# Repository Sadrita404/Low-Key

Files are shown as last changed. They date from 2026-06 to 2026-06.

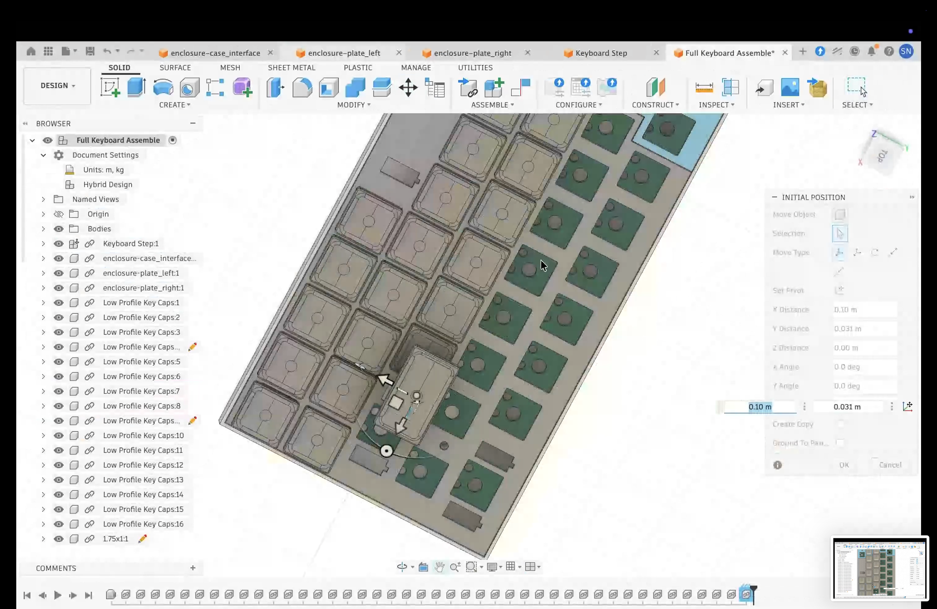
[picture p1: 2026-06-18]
IMAGES/22.png

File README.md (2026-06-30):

<div align="center">
  <table border="0" cellpadding="0" cellspacing="0">
    <tr>
      <td align="center" style="background: #ffffff; border: 1px solid #d0d7de; border-radius: 12px; padding: 16px; box-shadow: 0 4px 12px rgba(0,0,0,0.05);">
        Rough Layout For The PCB
        <div style="margin-top: 12px; font-family: -apple-system, BlinkMacSystemFont, 'Segoe UI', Helvetica, Arial, sans-serif; font-size: 13px; color: #57606a; font-weight: 500;">
      </td>
    </tr>
  </table>
</div>

|Title | Low Key |
|:-- |:--|
|Author | Sadrita Neogi|

## Overview
It is a 60% Low Profile Keyboard trying to build an mac magic keyboard alternative. And for this project I have choose the Promicro NRF52840 Controller Board as it is cost effective and easy to setup . I have also make this keyboard too low profile so that it can be easy to type in it . I have also make it battery powered and It can be worked over bluetooth that makes it very easy to use.

### Why I choose this project?
I have choose this project because I have a big fan of the Apple magic keyboard due to its low profile and good looking so from the starting I wanted to create something like which is low profile. But if I going to buy one, it would cost me a lot and I cannot customise it so I wanted to make something which is customisable, so I have made this in the 60% layout keyboard which is in the low profile and I love to make it and I have also made the PCB so I can customise it. I have also put my name on the PCB. And I have loved the whole process from designing in the PCB to making assembly file in fusion

<div id="-screenshots" align="center">
  <h3>PCB Design</h3>

  <table>
    <tr>
      <td>
        Full Board Layout
      </td>
      <td>
        Component Placement
      </td>
    </tr>
    <tr>
      <td>
        Trace Routing Detail
      </td>
      <td>
        Connection Map
      </td>
    </tr>
  </table>
</div>

<div id="-screenshots" align="center">
  <h3>PCB </h3>

  <table>
    <tr>
      <td>
        Full Board Layout
      </td>
      <td>
        Component Placement
      </td>
    </tr>
    <tr>
      <td>
        Trace Routing Detail
      </td>
      <td>
        Connection Map
      </td>
    </tr>
  </table>
</div>

<div id="-screenshots" align="center">
  <h3>CAD Work </h3>

  <table>
    <tr>
      <td>
        Full Board Layout
      </td>
      <td>
        Component Placement
      </td>
    </tr>
    <tr>
      <td>
        Trace Routing Detail
      </td>
      <td>
        Connection Map
      </td>
    </tr>
  </table>
</div>

<div id="-screenshots" align="center">
  <h3> Assembly CAD Work </h3>
  <table>
    <tr>
      <td>
        Full Board Layout
      </td>
      <td>
        Component Placement
      </td>
    </tr>
    <tr>
      <td>
        Trace Routing Detail
      </td>
      <td>
        Connection Map
      </td>
    </tr>
  </table>
</div>

<!-- FRONT & BACK VIEW SHOWCASE -->
<div align="center">
  <h2> Final Look After Assembly </h2>
</div>

---

<!-- TWO-COLUMN IMAGE FRAME GRID -->
<div align="center">
  <table border="0" cellpadding="10" cellspacing="0" style="border-collapse: collapse;">
    <tr>
      <!-- FRONT SIDE CARD -->
      <td align="center" valign="top" width="50%" style="background: #ffffff; border: 1px solid #d0d7de; border-radius: 12px; padding: 16px; box-shadow: 0 4px 12px rgba(0,0,0,0.05);">
        Front Side View
        
      </td>
      <!-- SPACER FOR GITHUB MOBILE DEGRADATION -->
      <td width="2%">&nbsp;</td>
      <!-- BACK SIDE CARD -->
      <td align="center" valign="top" width="50%" style="background: #ffffff; border: 1px solid #d0d7de; border-radius: 12px; padding: 16px; box-shadow: 0 4px 12px rgba(0,0,0,0.05);">
        Back Side View
        
      </td>
    </tr>
  </table>
</div>

<!-- TWO-COLUMN IMAGE FRAME GRID -->
<div align="center">
  <table border="0" cellpadding="10" cellspacing="0" style="border-collapse: collapse;">
    <tr>
      <!-- FRONT SIDE CARD -->
      <td align="center" valign="top" width="50%" style="background: #ffffff; border: 1px solid #d0d7de; border-radius: 12px; padding: 16px; box-shadow: 0 4px 12px rgba(0,0,0,0.05);">
        Front Side View
        
      </td>
      <!-- SPACER FOR GITHUB MOBILE DEGRADATION -->
      <td width="2%">&nbsp;</td>
      <!-- BACK SIDE CARD -->
      <td align="center" valign="top" width="50%" style="background: #ffffff; border: 1px solid #d0d7de; border-radius: 12px; padding: 16px; box-shadow: 0 4px 12px rgba(0,0,0,0.05);">
        Back Side View
        
      </td>
    </tr>
  </table>
</div>

<div align="center">
  <h2> Bill of Materials</h2>
</div>

| Component Name | Purpose | Qty | Unit Price | Total Price | Source Link |
| :--- | :--- | :---: | :---: | :---: | :---: |
| **3.7V 1000mAh Lipo Battery** | For Power | 1 | $4.00 | $4.00 | [Robu](https://robu.in/product/wly394058-1000mah-3-7v-single-cell-rechargeable-lipo-battery/) |
| **1N4148W - Diodes** | For PCB | 64 | $0.02 | $1.22 | [Robu](https://robu.in/product/1n4148w-slkor-75v-1v-4ns-150ma-sod-123-switching-diodes-rohs/) |
| **Header Pin** | For PCB | 2 | $0.58 | $1.16 | [Lion Circuits](https://www.lioncircuits.com/parts/M20-8770542) |
| **Switch Slide SPDT** | For Power On and OFF | 1 | $1.70 | $1.70 | [Lion Circuits](https://www.lioncircuits.com/parts/SSSS811101) |
| **Screw(M4x10mm)** | For Fixing | 4 | $0.023 | $0.093 | [Onlyscrew](https://onlyscrews.in/products/m4-x-10mm-hex-allen-button-head-high-tensile10-9-black-oxide-screw-dia-4mm-length-10mm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) |
| **Hot-swap Socket** | For the PCB | 64 | $0.10 | $6.15 | [Meckeys](https://meckeys.com/shop/accessories/keyboard-accessories/key-switches/kailh-hot-swap-socket/) |
| **Plate Mount Stabilizers** | For the Keys | 2 | $2.10 | $4.20 | [GenesisPC](https://www.genesispc.in/products/durock-plate-mount-stabilizers-6-25u-4x2u-black) |
| **Promicro NRF52840** | Main Controller Board | 1 | $8.05 | $8.05 | [Robu](https://robu.in/product/promicro-nrf52840-development-board/) |
| **Keycaps** | For adding on the switches | 64 | $0.33 | $21.20 | [CtrlShiftStore](https://ctrlshiftstore.com/products/xvx-skyline-r2) |
| **3 pin Low Profile Switch** | For the PCB board | 64 | $0.20 | $12.70 | [Meckeys](https://meckeys.com/shop/accessories/keyboard-accessories/key-switches/gateron-low-profile-2-0-mechanical-switch-3pin/) |
| **PCB** | Main Board | 1 | $16.00 | $16.00 | [JLCPCB](https://jlcpcb.com/) |
| **Total Project Cost** | | | | **$76.38** | |

<div align="center">
  <table border="0" cellpadding="0" cellspacing="0" style="border-collapse: collapse; max-width: 600px;">
    <tr>
      <td style="background: #ffffff; border: 1px solid #d0d7de; border-radius: 12px; padding: 20px; box-shadow: 0 4px 12px rgba(0,0,0,0.05); font-family: -apple-system, BlinkMacSystemFont, 'Segoe UI', Helvetica, Arial, sans-serif;">
        <div style="font-size: 16px; font-weight: 600; color: #24292f; margin-bottom: 12px; border-bottom: 1px solid #d0d7de; padding-bottom: 8px;">
          Final Bill
        </div>
        <table width="100%" border="0" style="border-collapse: collapse; font-size: 14px; color: #57606a;">
          <tr>
            <td style="padding: 4px 0;">Component Subtotal:</td>
            <td align="right" style="font-weight: 500; color: #24292f;">$76.38</td>
          </tr>
          <tr>
            <td style="padding: 4px 0;"> Shipping:</td>
            <td align="right" style="font-weight: 500; color: #24292f;">$21.19</td>
          </tr>
          <tr>
            <td style="padding: 4px 0; padding-bottom: 8px;"> Tax:</td>
            <td align="right" style="font-weight: 500; color: #24292f;">$2</td>
          </tr>
          <tr style="border-top: 1px dashed #d0d7de;">
            <td style="padding: 12px 0 0 0; font-weight: 600; color: #24292f; font-size: 15px;">Net Total Cost:</td>
            <td align="right" style="padding: 12px 0 0 0; font-weight: bold; color: #2da44e; font-size: 18px;">$99.57</td>
          </tr>
          <tr>
            <td style="padding: 2px 0 0 0; font-size: 11px; color: #8c959f;">Projected Budget Allocation:</td>
            <td align="right" style="padding: 2px 0 0 0; font-weight: 500; font-size: 12px; color: #8c959f;">$100</td>
          </tr>
        </table>
      </td>
    </tr>
  </table>
</div>

I have provided the links to the parts that I will self - sourced , So that if a reader wanted to recreate this project they would be able to find all the parts..
Which is also updated on the BOM csv file too..

**Project Under Hack Club**

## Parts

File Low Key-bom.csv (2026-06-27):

Name | Purpose | Quantity | Total Cost (USD) | Link | Distributor
3.7V 1000mAh | For Power | 1 | 4.00 | https://robu.in/product/wly394058-1000mah-3-7v-single-cell-rechargeable-lipo-battery/?gad_source=1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 | robu
1N4148W - Diodes | For PCB | 64 | 1.22 | https://robu.in/product/1n4148w-slkor-75v-1v-4ns-150ma-sod-123-switching-diodes-rohs/?gad_source=1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 | robu
Header Pin | For PCB | 2 | 1.16 | https://www.lioncircuits.com/parts/M20-8770542 | lioncircuits
Switch Slide SPDT | For Power On and OFF | 1 | 1.70 | https://www.lioncircuits.com/parts/SSSS811101 | lioncircuits
Screw(M4x10mm) | For Fixing | 4 | 0.093 | https://onlyscrews.in/products/m4-x-10mm-hex-allen-button-head-high-tensile10-9-black-oxide-screw-dia-4mm-length-10mm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 | Self Sourced
Hot-swap Socket | For the PCb | 64 | 6.15 | https://meckeys.com/shop/accessories/keyboard-accessories/key-switches/kailh-hot-swap-socket/?utm_term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 | meckeys
Plate Mount Stabilizers | For the Keys | 2 | 4.20 | https://www.genesispc.in/products/durock-plate-mount-stabilizers-6-25u-4x2u-black?variant=43389442261045 | genesispc
Promicro NRF52840 | Main Controller Board | 1 | 8.05 | https://robu.in/product/promicro-nrf52840-development-board/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 | robu
Keycaps | For adding on the switches | 64 | 21.20 | https://ctrlshiftstore.com/products/xvx-skyline-r2?variant=44385147977821 | ctrlshiftstore
3 pin Low Profile Switch | For the PCB board | 64 | 12.70 | https://meckeys.com/shop/accessories/keyboard-accessories/key-switches/gateron-low-profile-2-0-mechanical-switch-3pin/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 | meckeys
PCB | Main Board | 1 | 16.00 | https://jlcpcb.com/ | jlcpcb

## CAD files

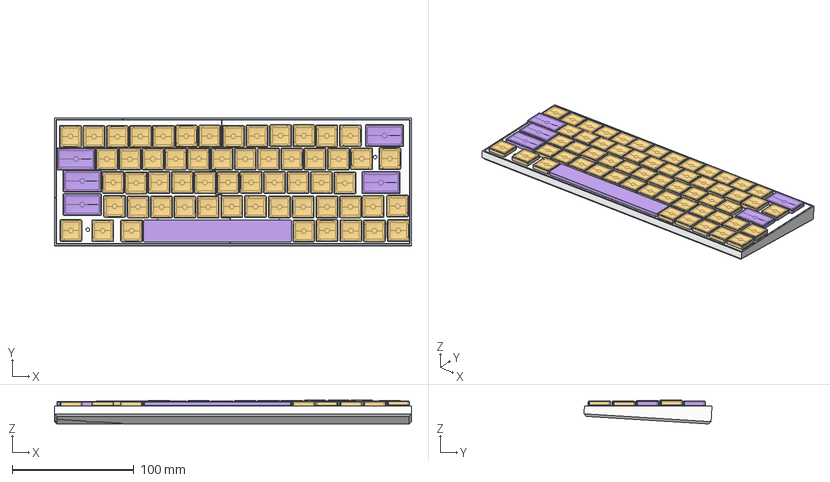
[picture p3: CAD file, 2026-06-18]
CAD/Full Keyboard Assemble.step
292.8 x 105.0 x 19.6 mm
D_SOD-123 x 64
low key_PCB
case_interface
plate_left
plate_right
1.75x1 x 5

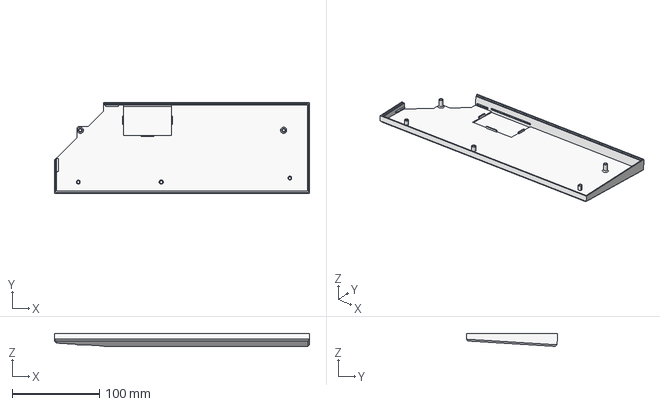
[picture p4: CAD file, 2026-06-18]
CAD/enclosure-main_case.step
292.8 x 105.0 x 14.7 mm

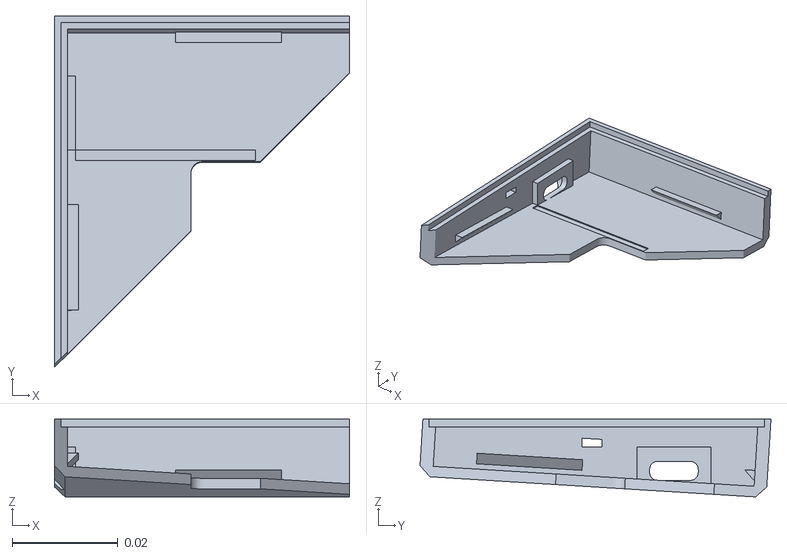
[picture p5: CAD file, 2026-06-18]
STL/Corner Case.stl
0.0558 x 0.0664 x 0.0147

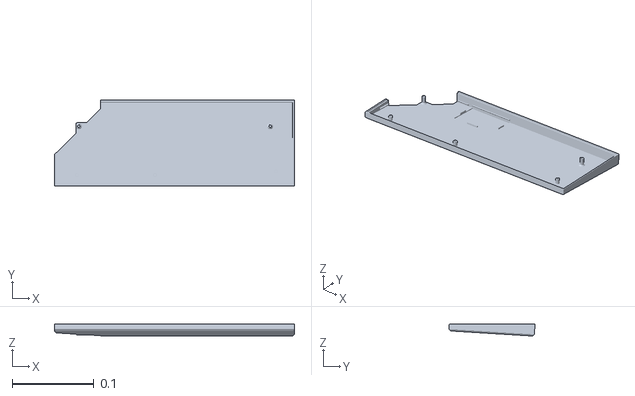
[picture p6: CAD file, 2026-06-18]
STL/Base Case.stl
0.293 x 0.105 x 0.0147

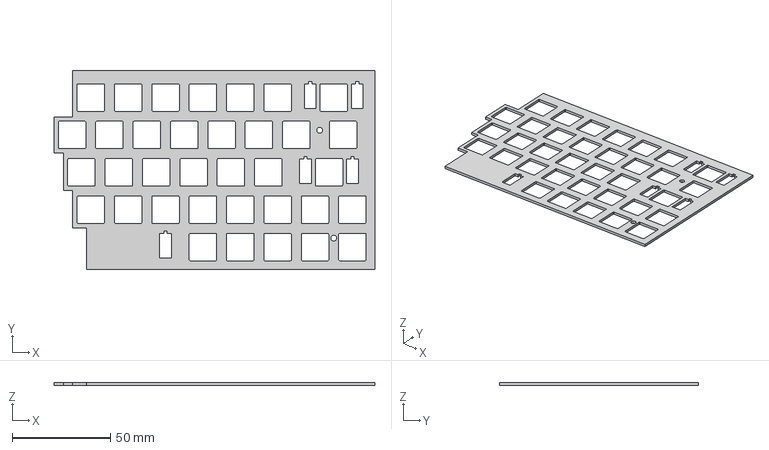
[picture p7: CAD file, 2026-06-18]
CAD/enclosure-plate_right.step
163.6 x 101.6 x 1.50 mm

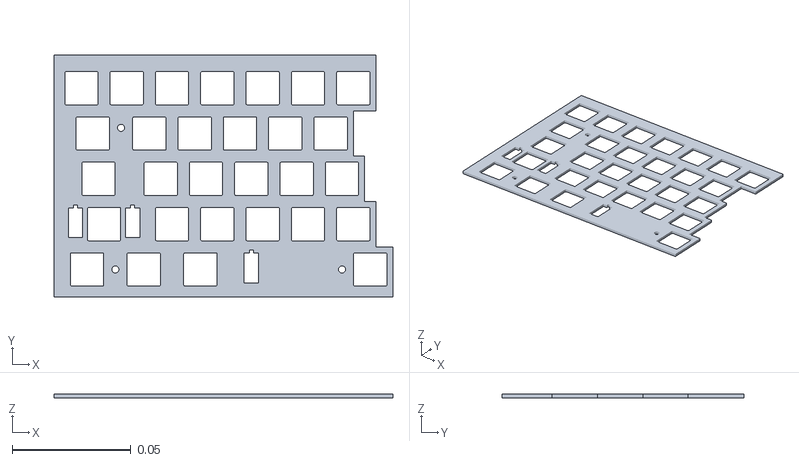
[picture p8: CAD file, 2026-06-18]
STL/Top Left Plate.stl
0.142 x 0.102 x 0.0015

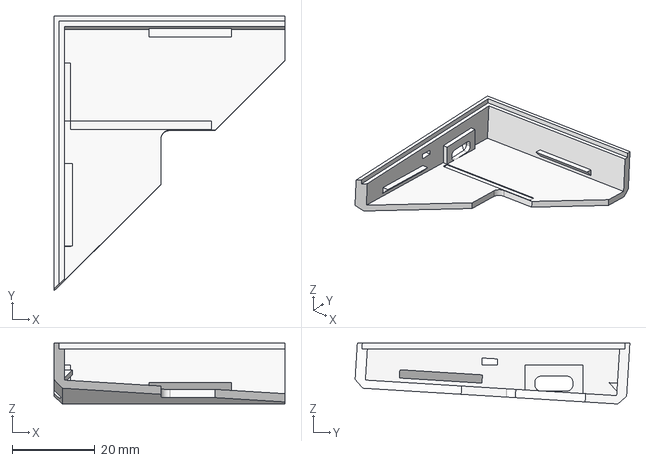
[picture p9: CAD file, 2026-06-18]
CAD/enclosure-case_interface.step
55.8 x 66.4 x 14.7 mm

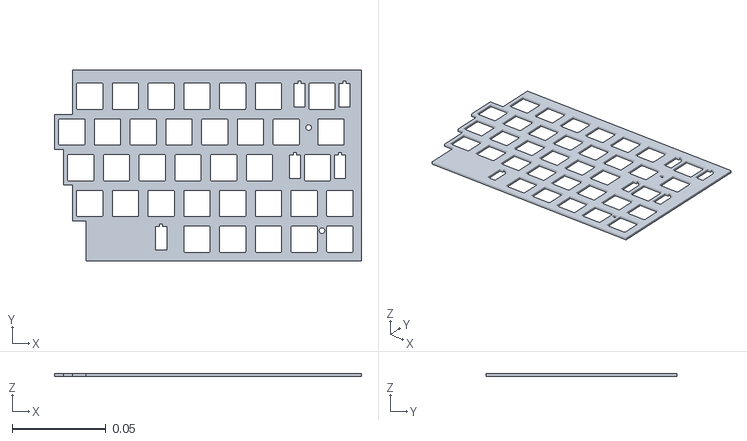
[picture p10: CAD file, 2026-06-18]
STL/Top Right Plate.stl
0.164 x 0.102 x 0.0015

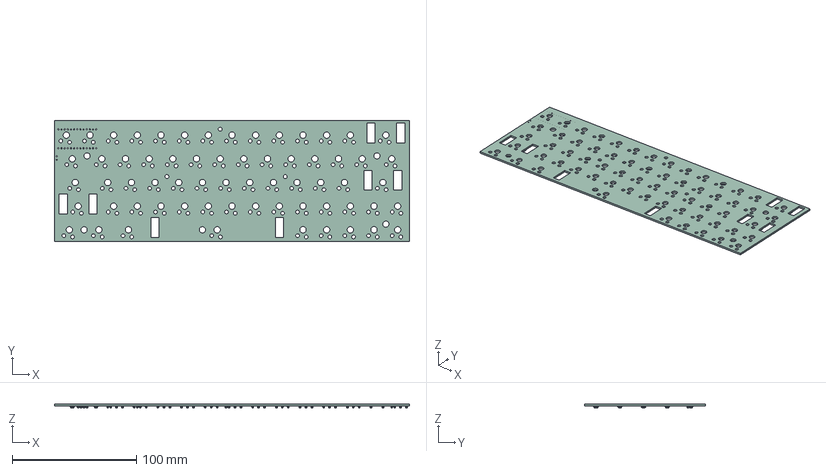
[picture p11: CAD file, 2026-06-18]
CAD/Keyboard .step
285.8 x 97.6 x 2.85 mm
D_SOD-123 x 64
low key_PCB

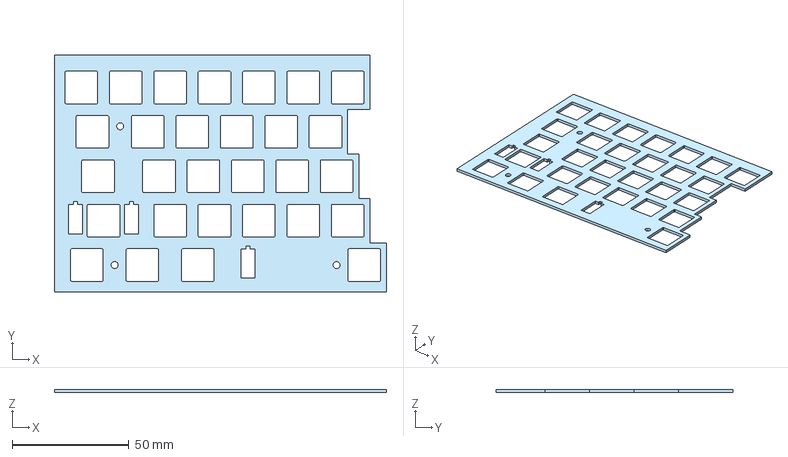
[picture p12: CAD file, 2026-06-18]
CAD/enclosure-plate_left.step
142.5 x 101.6 x 1.50 mm

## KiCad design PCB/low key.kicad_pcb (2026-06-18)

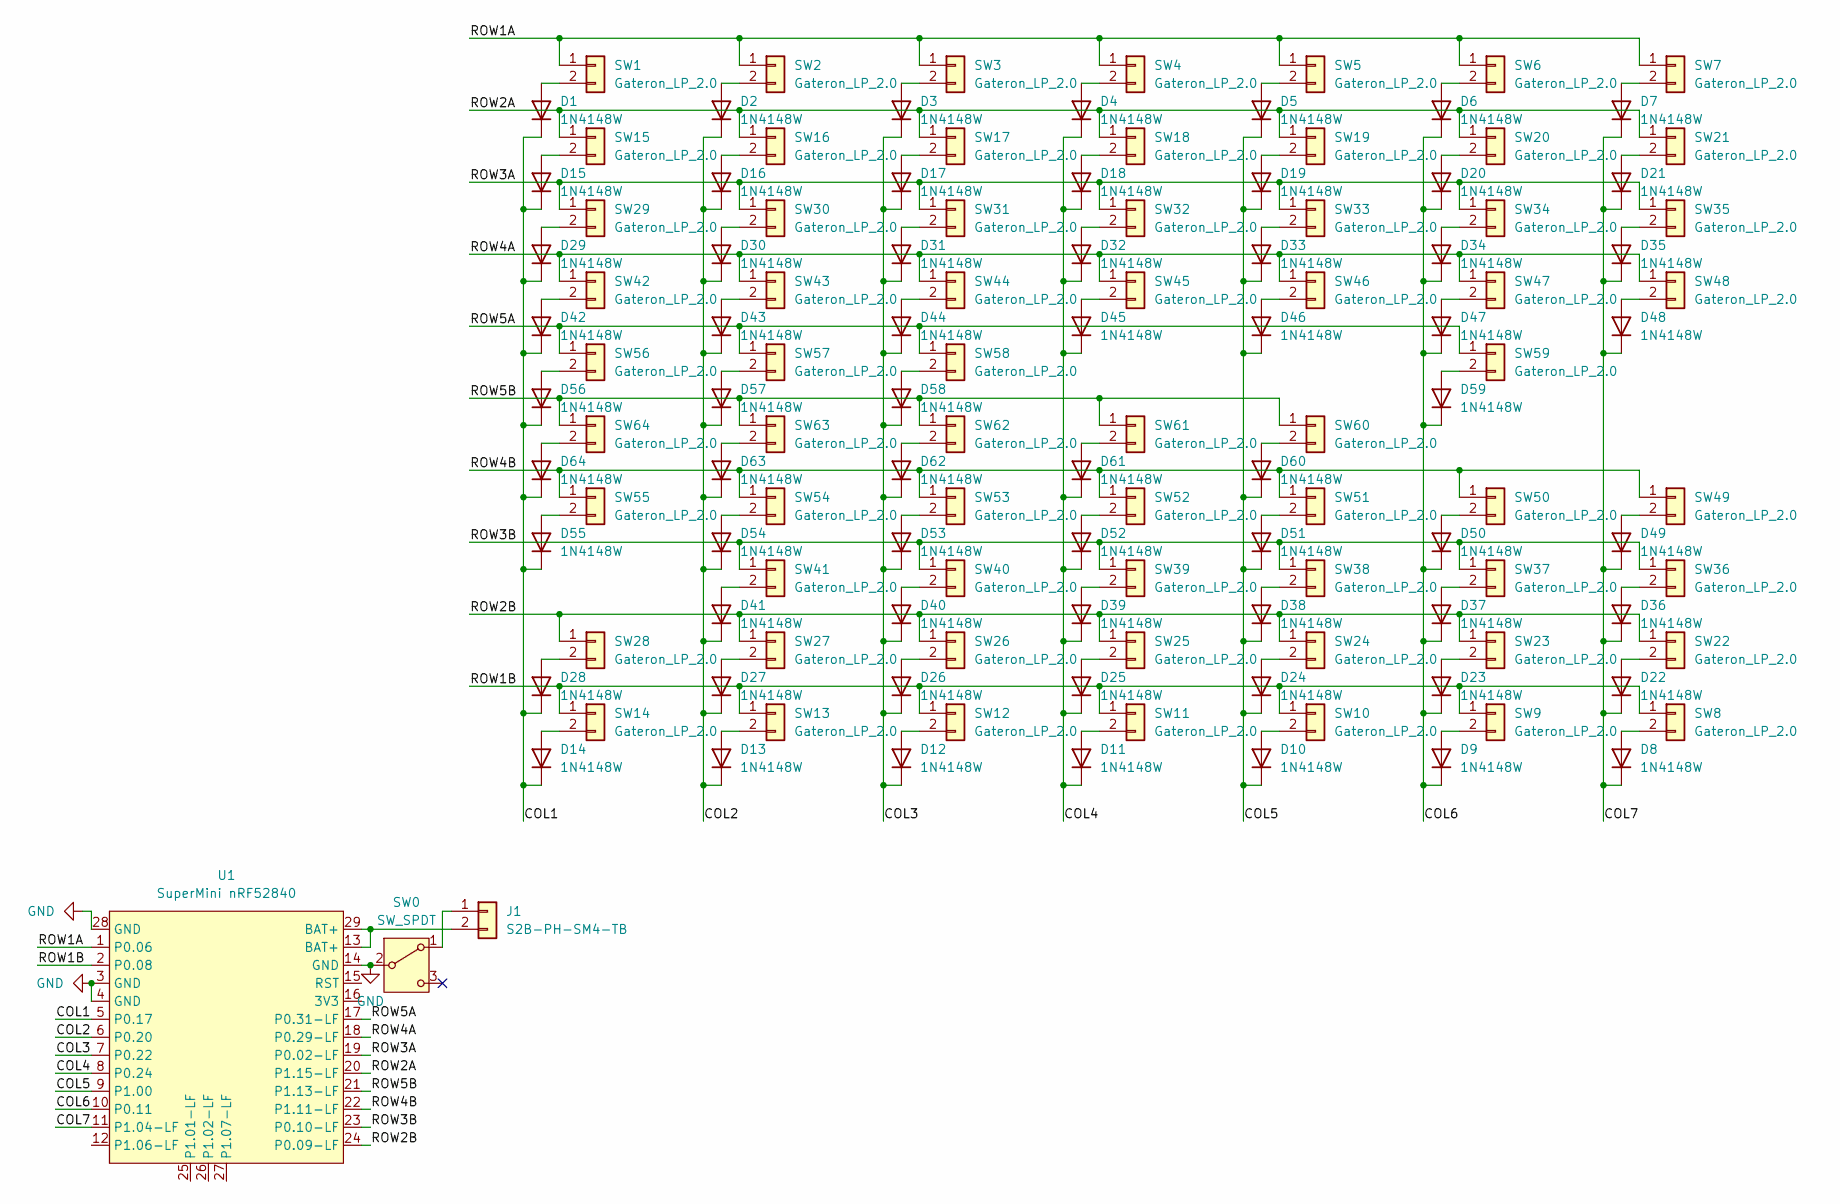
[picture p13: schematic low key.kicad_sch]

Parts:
D1, D2, D3, D4, D5, D6, D7, D8, D9, D10, D11, D12, D13, D14, D15, D16, D17, D18, D19, D20, D21, D22, D23, D24, D25, D26, D27, D28, D29, D30, D31, D32, D33, D34, D35, D36, D37, D38, D39, D40, D41, D42, D43, D44, D45, D46, D47, D48, D49, D50, D51, D52, D53, D54, D55, D56, D57, D58, D59, D60, D61, D62, D63, D64: 1N4148W; D_SOD-123
J1: S2B-PH-SM4-TB; JST_PH_S2B-PH-SM4-TB_1x02-1MP_P2.00mm_Horizontal
SW0: SW_SPDT; SW_SSSS811101
SW1, SW2, SW3, SW4, SW5, SW6, SW7, SW8, SW9, SW10, SW11, SW12, SW13, SW14, SW15, SW16, SW17, SW18, SW19, SW20, SW21, SW22, SW23, SW24, SW25, SW26, SW27, SW28, SW29, SW30, SW31, SW32, SW33, SW34, SW35, SW36, SW37, SW38, SW39, SW40, SW41, SW42, SW43, SW44, SW45, SW46, SW47, SW48, SW49, SW50, SW51, SW52, SW53, SW54, SW55, SW56, SW57, SW58, SW59, SW60, SW61, SW62, SW63, SW64: Gateron_LP_2.0
U1: SuperMini nRF52840; SuperMini_nRF52840_AH_USBup

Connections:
/COL1: D1.1 (K), D14.1 (K), D15.1 (K), D28.1 (K), D29.1 (K), D42.1 (K), D55.1 (K), D56.1 (K), D64.1 (K), U1.5 (P0.17)
/COL2: D2.1 (K), D13.1 (K), D16.1 (K), D27.1 (K), D30.1 (K), D41.1 (K), D43.1 (K), D54.1 (K), D57.1 (K), D63.1 (K), U1.6 (P0.20)
/COL3: D3.1 (K), D12.1 (K), D17.1 (K), D26.1 (K), D31.1 (K), D40.1 (K), D44.1 (K), D53.1 (K), D58.1 (K), D62.1 (K), U1.7 (P0.22)
/COL4: D4.1 (K), D11.1 (K), D18.1 (K), D25.1 (K), D32.1 (K), D39.1 (K), D45.1 (K), D52.1 (K), D61.1 (K), U1.8 (P0.24)
/COL5: D5.1 (K), D10.1 (K), D19.1 (K), D24.1 (K), D33.1 (K), D38.1 (K), D46.1 (K), D51.1 (K), D60.1 (K), U1.9 (P1.00)
/COL6: D6.1 (K), D9.1 (K), D20.1 (K), D23.1 (K), D34.1 (K), D37.1 (K), D47.1 (K), D50.1 (K), D59.1 (K), U1.10 (P0.11)
/COL7: D7.1 (K), D8.1 (K), D21.1 (K), D22.1 (K), D35.1 (K), D36.1 (K), D48.1 (K), D49.1 (K), U1.11 (P1.04-LF)
/ROW1A: SW1.1, SW2.1, SW3.1, SW4.1, SW5.1, SW6.1, SW7.1, U1.1 (P0.06)
/ROW1B: SW8.1, SW9.1, SW10.1, SW11.1, SW12.1, SW13.1, SW14.1, U1.2 (P0.08)
/ROW2A: SW15.1, SW16.1, SW17.1, SW18.1, SW19.1, SW20.1, SW21.1, U1.20 (P1.15-LF)
/ROW2B: SW22.1, SW23.1, SW24.1, SW25.1, SW26.1, SW27.1, SW28.1, U1.24 (P0.09-LF)
/ROW3A: SW29.1, SW30.1, SW31.1, SW32.1, SW33.1, SW34.1, SW35.1, U1.19 (P0.02-LF)
/ROW3B: SW36.1, SW37.1, SW38.1, SW39.1, SW40.1, SW41.1, U1.23 (P0.10-LF)
/ROW4A: SW42.1, SW43.1, SW44.1, SW45.1, SW46.1, SW47.1, SW48.1, U1.18 (P0.29-LF)
/ROW4B: SW49.1, SW50.1, SW51.1, SW52.1, SW53.1, SW54.1, SW55.1, U1.22 (P1.11-LF)
/ROW5A: SW56.1, SW57.1, SW58.1, SW59.1, U1.17 (P0.31-LF)
/ROW5B: SW60.1, SW61.1, SW62.1, SW63.1, SW64.1, U1.21 (P1.13-LF)
GND: SW0.2 (B), U1.3 (GND), U1.4 (GND), U1.14 (GND), U1.28 (GND)
unnamed: D1.2 (A), SW1.2
unnamed: D2.2 (A), SW2.2
unnamed: D3.2 (A), SW3.2
unnamed: D4.2 (A), SW4.2
unnamed: D5.2 (A), SW5.2
unnamed: D6.2 (A), SW6.2
unnamed: D7.2 (A), SW7.2
unnamed: D8.2 (A), SW8.2
unnamed: D9.2 (A), SW9.2
unnamed: D10.2 (A), SW10.2
unnamed: D11.2 (A), SW11.2
unnamed: D12.2 (A), SW12.2
unnamed: D13.2 (A), SW13.2
unnamed: D14.2 (A), SW14.2
unnamed: D15.2 (A), SW15.2
unnamed: D16.2 (A), SW16.2
unnamed: D17.2 (A), SW17.2
unnamed: D18.2 (A), SW18.2
unnamed: D19.2 (A), SW19.2
unnamed: D20.2 (A), SW20.2
unnamed: D21.2 (A), SW21.2
unnamed: D22.2 (A), SW22.2
unnamed: D23.2 (A), SW23.2
unnamed: D24.2 (A), SW24.2
unnamed: D25.2 (A), SW25.2
unnamed: D26.2 (A), SW26.2
unnamed: D27.2 (A), SW27.2
unnamed: D28.2 (A), SW28.2
unnamed: D29.2 (A), SW29.2
unnamed: D30.2 (A), SW30.2
unnamed: D31.2 (A), SW31.2
unnamed: D32.2 (A), SW32.2
unnamed: D33.2 (A), SW33.2
unnamed: D34.2 (A), SW34.2
unnamed: D35.2 (A), SW35.2
unnamed: D36.2 (A), SW36.2
unnamed: D37.2 (A), SW37.2
unnamed: D38.2 (A), SW38.2
unnamed: D39.2 (A), SW39.2
unnamed: D40.2 (A), SW40.2
unnamed: D41.2 (A), SW41.2
unnamed: D42.2 (A), SW42.2
unnamed: D43.2 (A), SW43.2
unnamed: D44.2 (A), SW44.2
unnamed: D45.2 (A), SW45.2
unnamed: D46.2 (A), SW46.2
unnamed: D47.2 (A), SW47.2
unnamed: D48.2 (A), SW48.2
unnamed: D49.2 (A), SW49.2
unnamed: D50.2 (A), SW50.2
unnamed: D51.2 (A), SW51.2
unnamed: D52.2 (A), SW52.2
unnamed: D53.2 (A), SW53.2
unnamed: D54.2 (A), SW54.2
unnamed: D55.2 (A), SW55.2
unnamed: D56.2 (A), SW56.2
unnamed: D57.2 (A), SW57.2
unnamed: D58.2 (A), SW58.2
unnamed: D59.2 (A), SW59.2
unnamed: D60.2 (A), SW60.2
unnamed: D61.2 (A), SW61.2
unnamed: D62.2 (A), SW62.2
unnamed: D63.2 (A), SW63.2
unnamed: D64.2 (A), SW64.2
unnamed: J1.1, SW0.1 (A)
unnamed: J1.2, U1.13 (BAT+), U1.29 (BAT+)

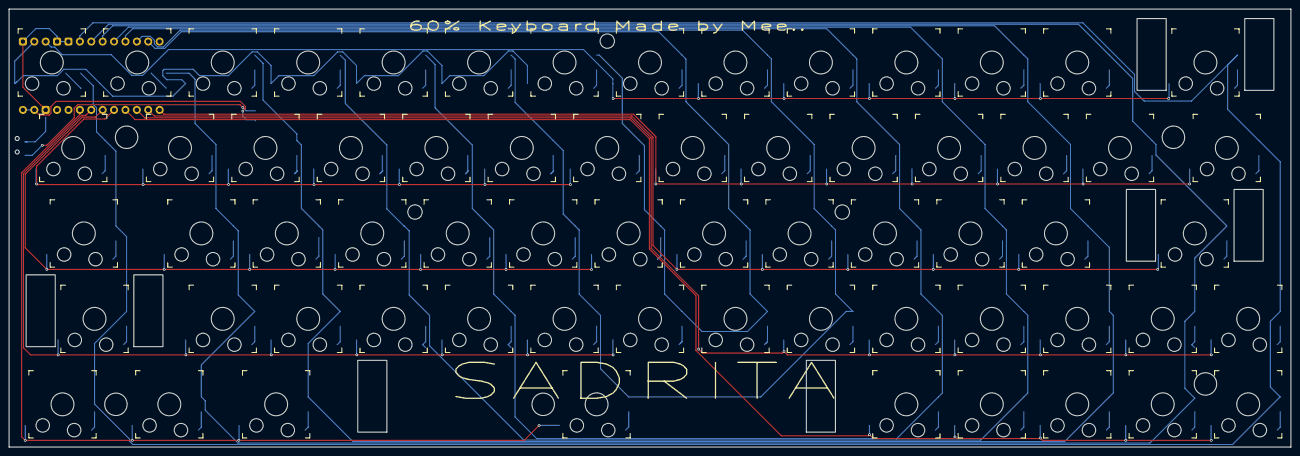
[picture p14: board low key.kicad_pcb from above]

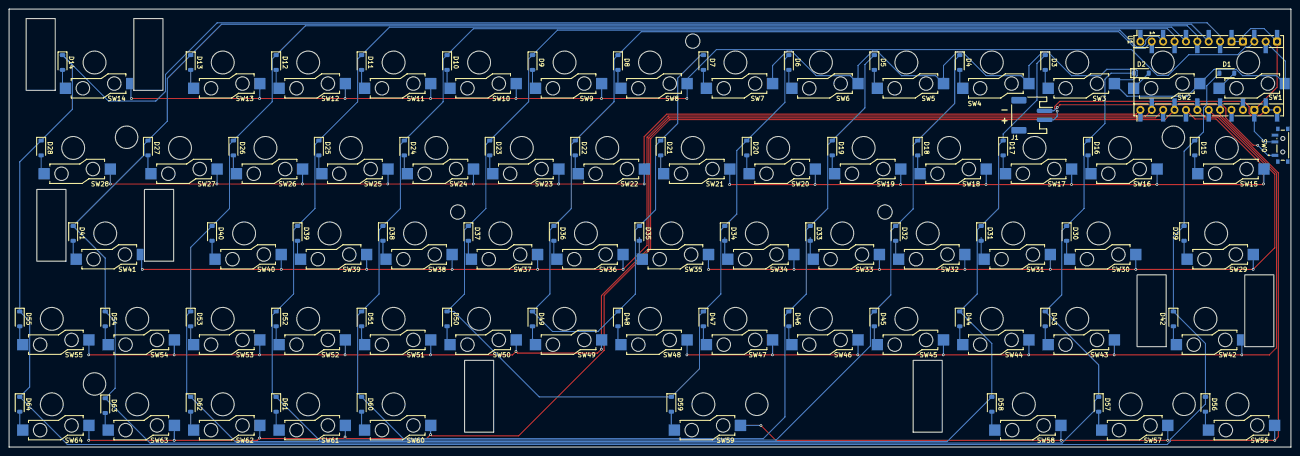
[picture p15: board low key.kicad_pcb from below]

Board: 2 copper layers, 285.8 x 97.6 mm, 131 parts (67 on the bottom side), 84 nets.

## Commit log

2026-06-18 CAD all step file added
2026-06-18 PCB GERBER added
2026-06-18 all STL file for print added
2026-06-19 Gerber zip added
2026-06-27 Update Low Key-bom.csv
    [Low Key-bom.csv]
